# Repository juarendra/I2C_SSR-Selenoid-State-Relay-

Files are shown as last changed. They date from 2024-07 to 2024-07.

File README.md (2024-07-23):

# I2C_SSR-Selenoid-State-Relay-
## Table of Content

* [Product Specsification](#product-specsification)
* [Technical Spesification](#technical-spesification)
* [Priview Hardware](#priview-hardware)
* [Documentation](#documentation)
  * [Pinout Diagram](#pinout-diagram)
  * [Dimension](#dimension)
  * [BOM](#bom)
  * [Schematic](#schematic0)
  * [Example Program](#examples-program)
* [FAQ](#FAQ)

## Priview Hardware
<p align="center">
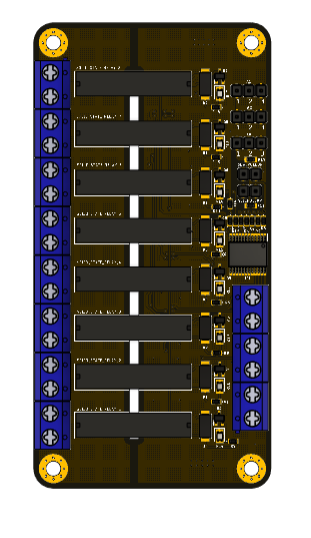
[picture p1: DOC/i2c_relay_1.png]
  
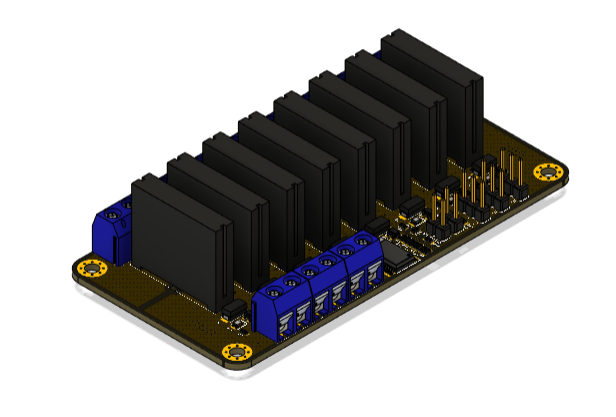
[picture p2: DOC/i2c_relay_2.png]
  
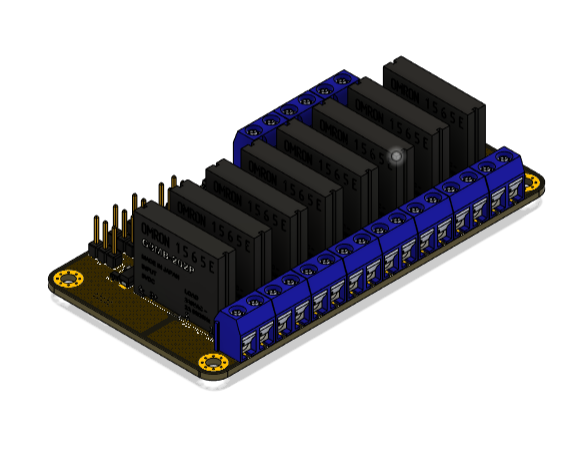
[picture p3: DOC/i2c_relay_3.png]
  
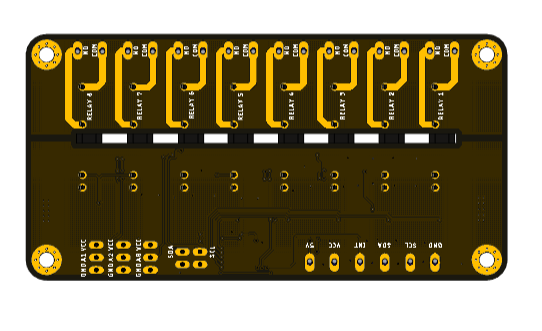
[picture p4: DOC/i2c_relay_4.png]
  
</p>

## Documentation
### Pinout Diagram
<p align="center">
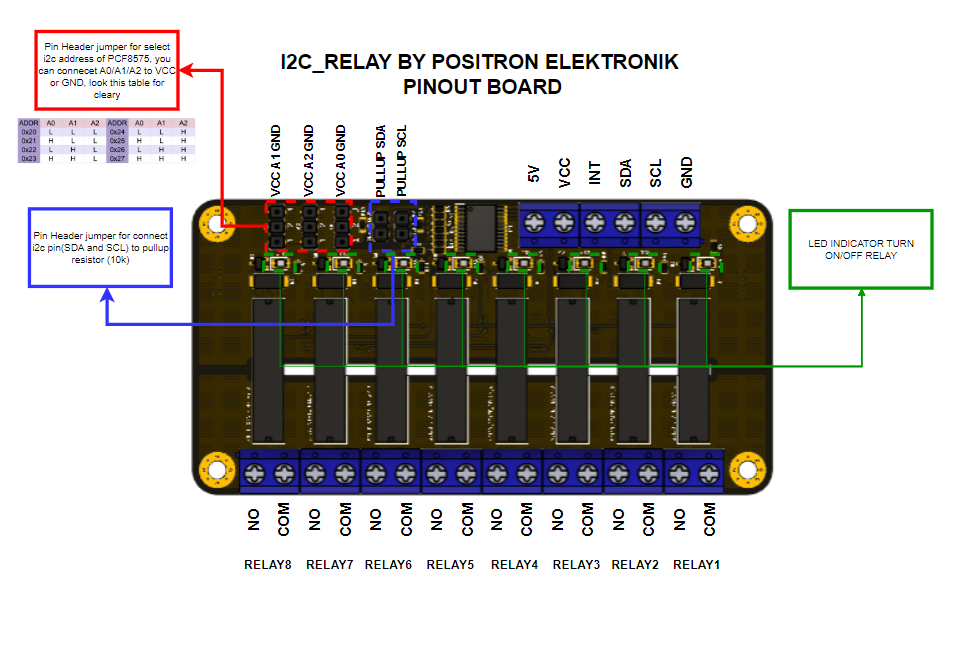
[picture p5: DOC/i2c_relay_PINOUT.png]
  
</p>

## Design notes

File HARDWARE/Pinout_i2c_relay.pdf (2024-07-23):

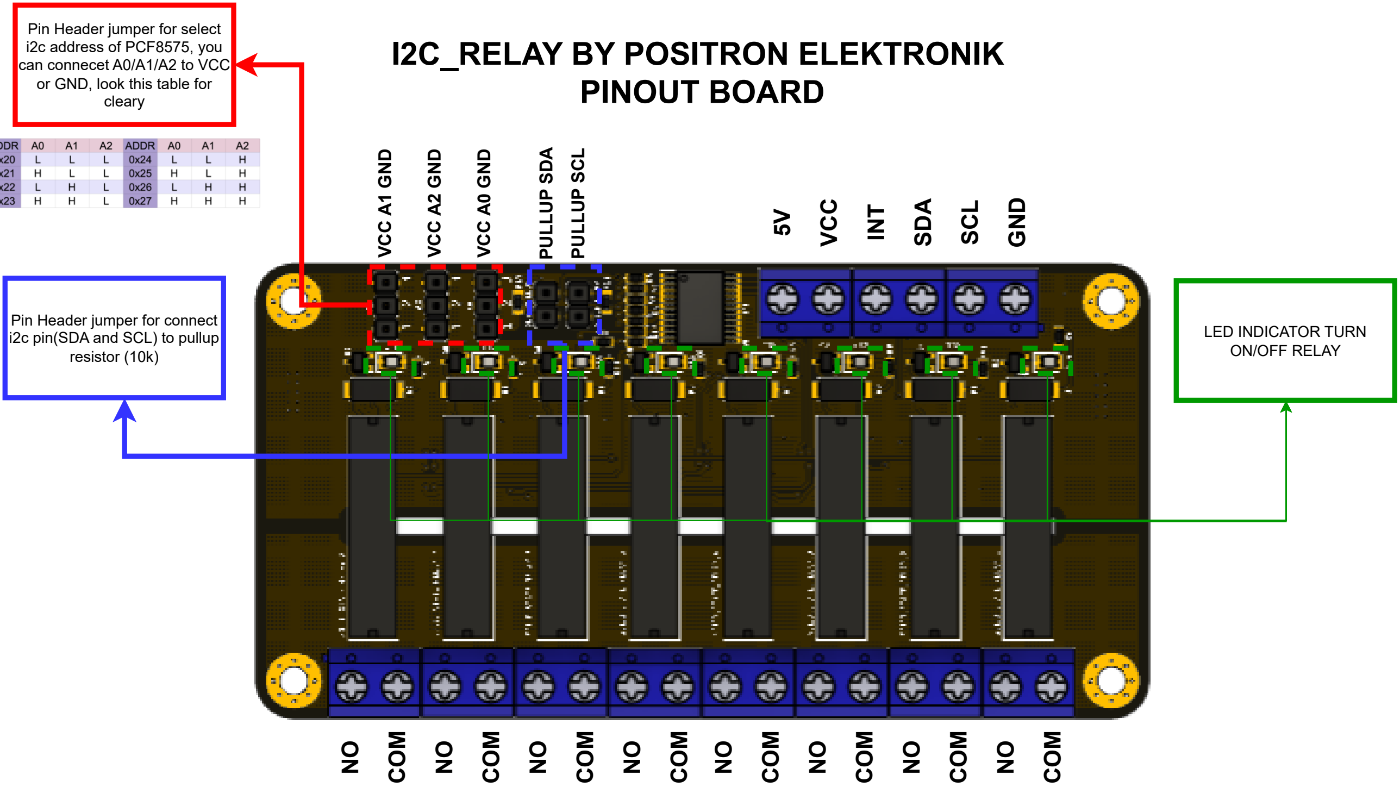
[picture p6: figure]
I2C_RELAY BY POSITRON ELEKTRONIK PINOUT BOARD; COM; VCC; INT; SDA; SCL; GND; Pin Header jumper for select i2c address of PCF8575, you can connecet A0/A1/A2 to VCC or GND, look this table for cleary; Pin Header jumper for connect i2c pin(SDA and SCL) to pullup resistor (10k); LED INDICATOR TURN ON/OFF RELAY

RELAY8 RELAY7 RELAY6 RELAY5 | RELAY4 RELAY3 RELAY2 RELAY1 VCC A¹ GND | VCC A² GND | VCC A⁰ GND | PULLUP SDA PULLUP SCL

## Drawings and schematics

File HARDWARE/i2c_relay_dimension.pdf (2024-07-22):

21.65

1.57

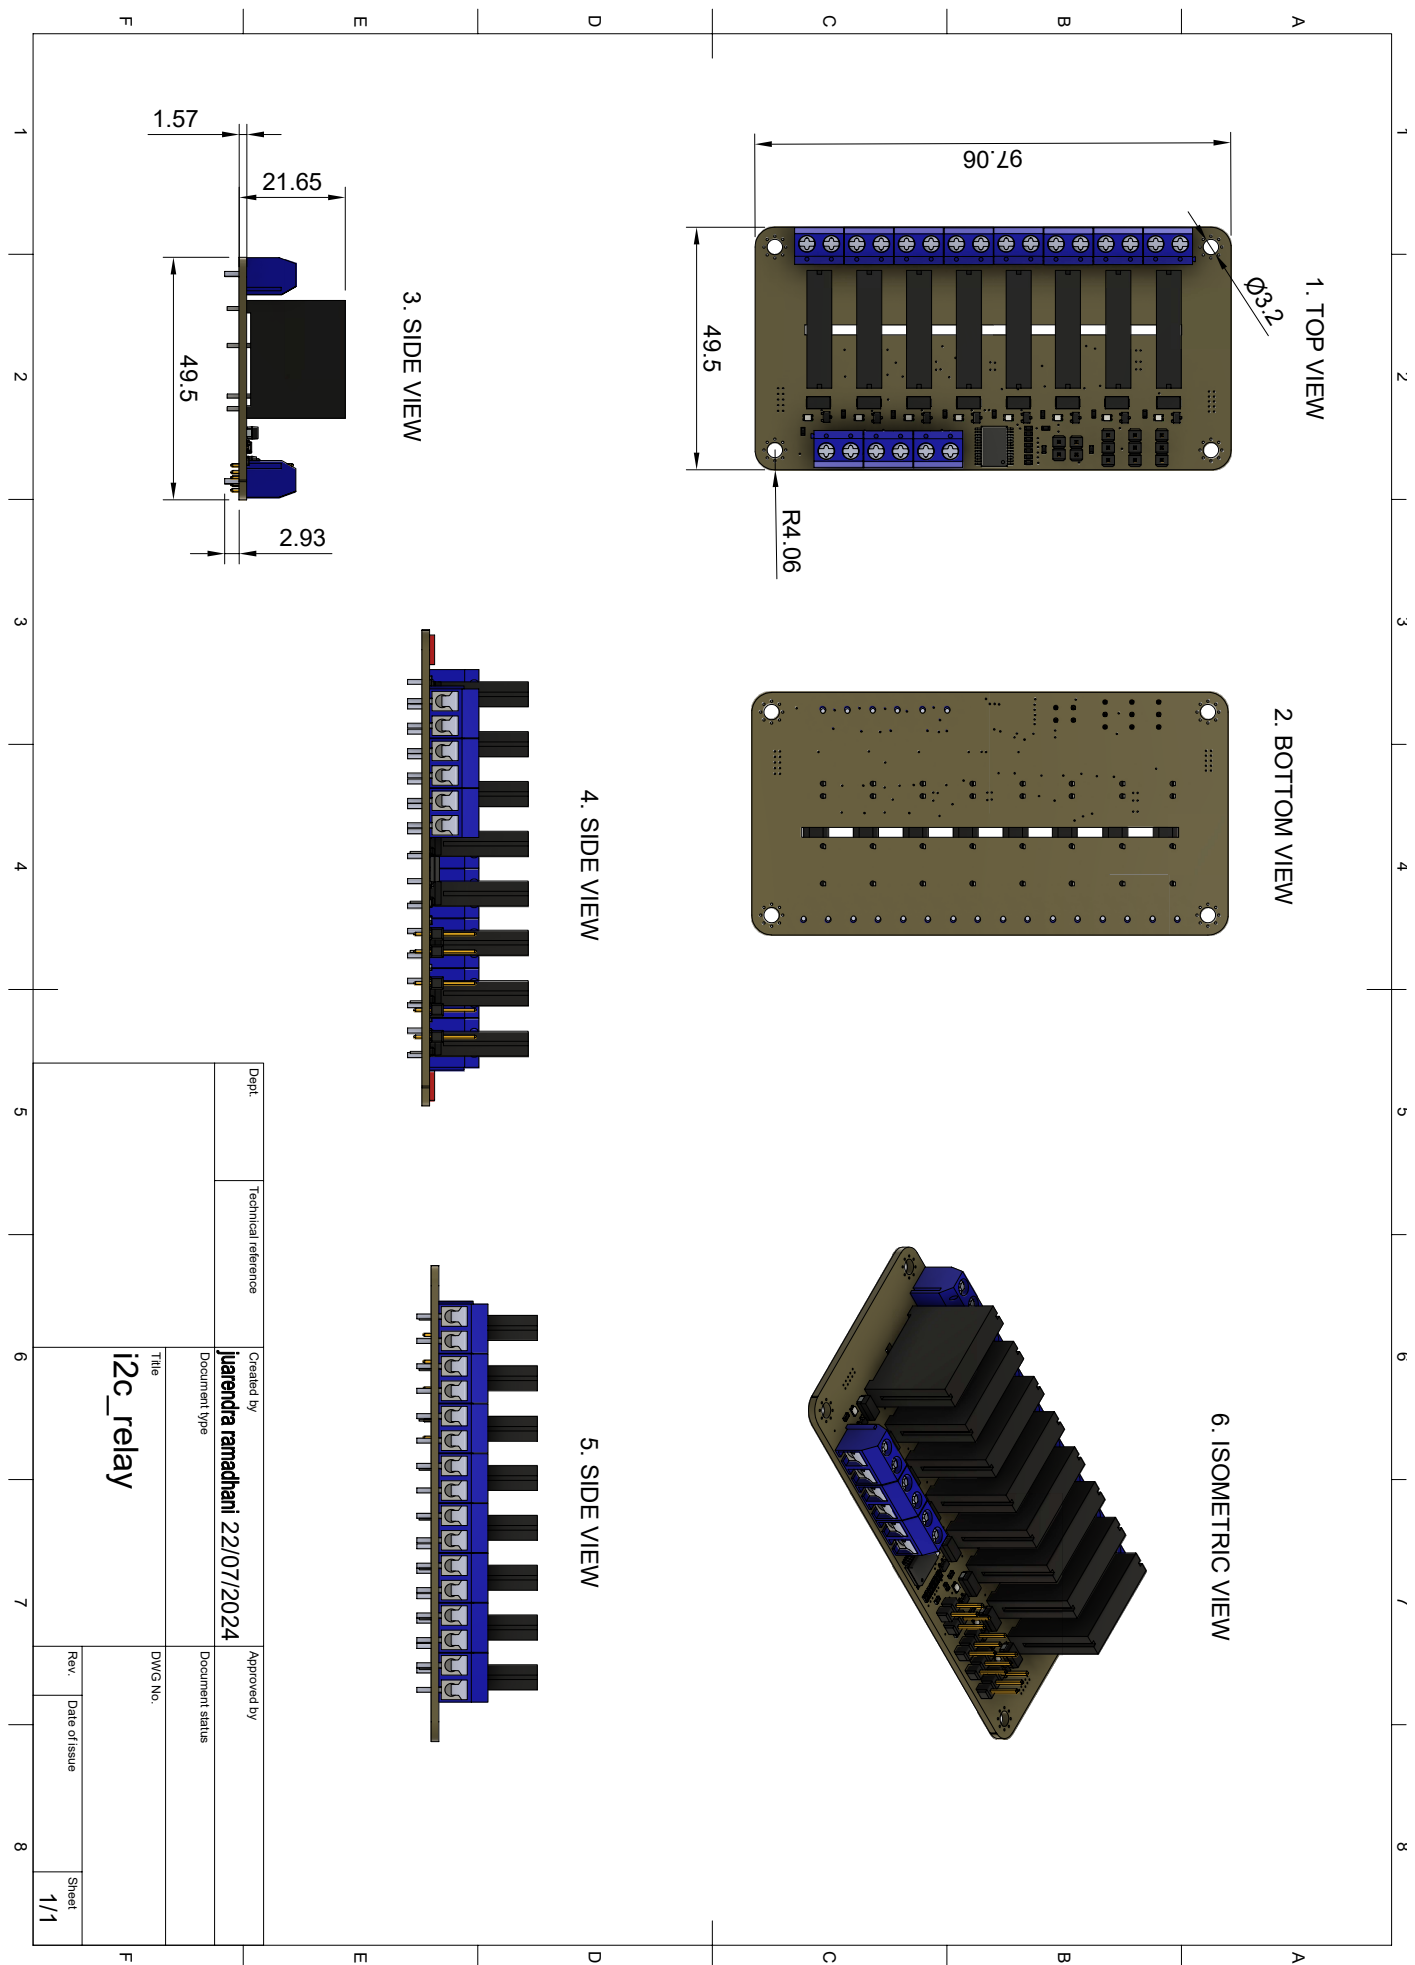
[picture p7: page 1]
1. TOP VIEW ³. SIDE VIEW; 4. SIDE VIEW 5. SIDE VIEW; 2. BOTTOM VIEW 6. ISOMETRIC VIEW

1 A 2 3 4 5 6 7 8 1 2 3 4 5 6 7 8 FEDCB FEDCBA Dept. Technical reference Created by Approved by Title DWG No. Document type Document status Rev. Date of issue Sheet 22/07/2024 1/1 i2c_relay Ø3.2

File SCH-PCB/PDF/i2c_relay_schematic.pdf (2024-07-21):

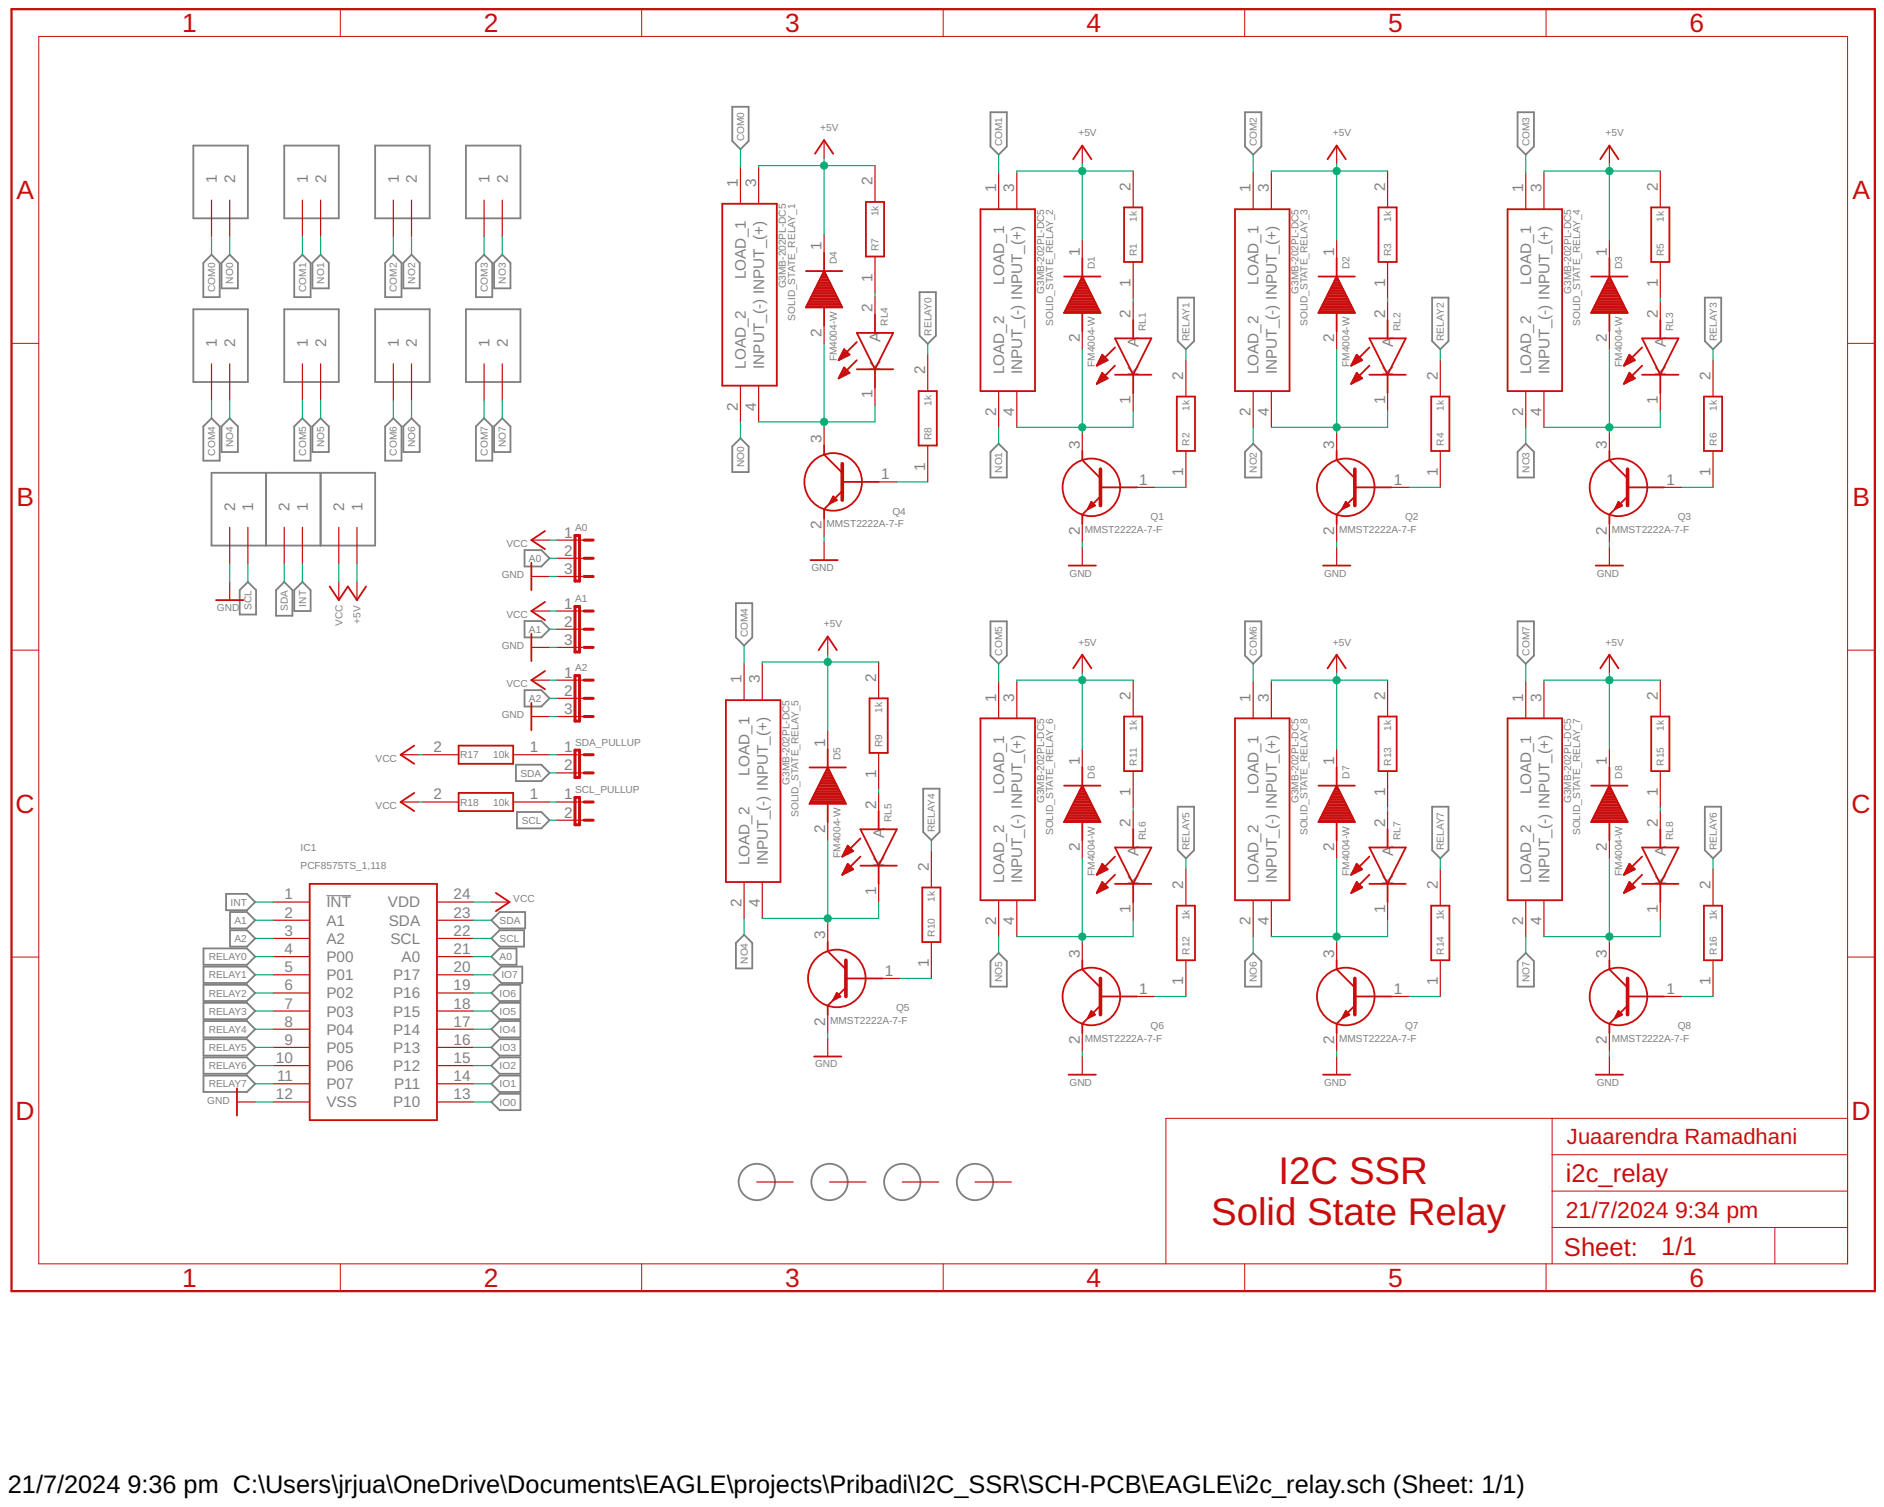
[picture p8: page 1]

21/7/2024 9:36 pm C:\Users\jrjua\OneDrive\Documents\EAGLE\projects\Pribadi\I2C_SSR\SCH-PCB\EAGLE\i2c_relay.sch (Sheet: 1/1)

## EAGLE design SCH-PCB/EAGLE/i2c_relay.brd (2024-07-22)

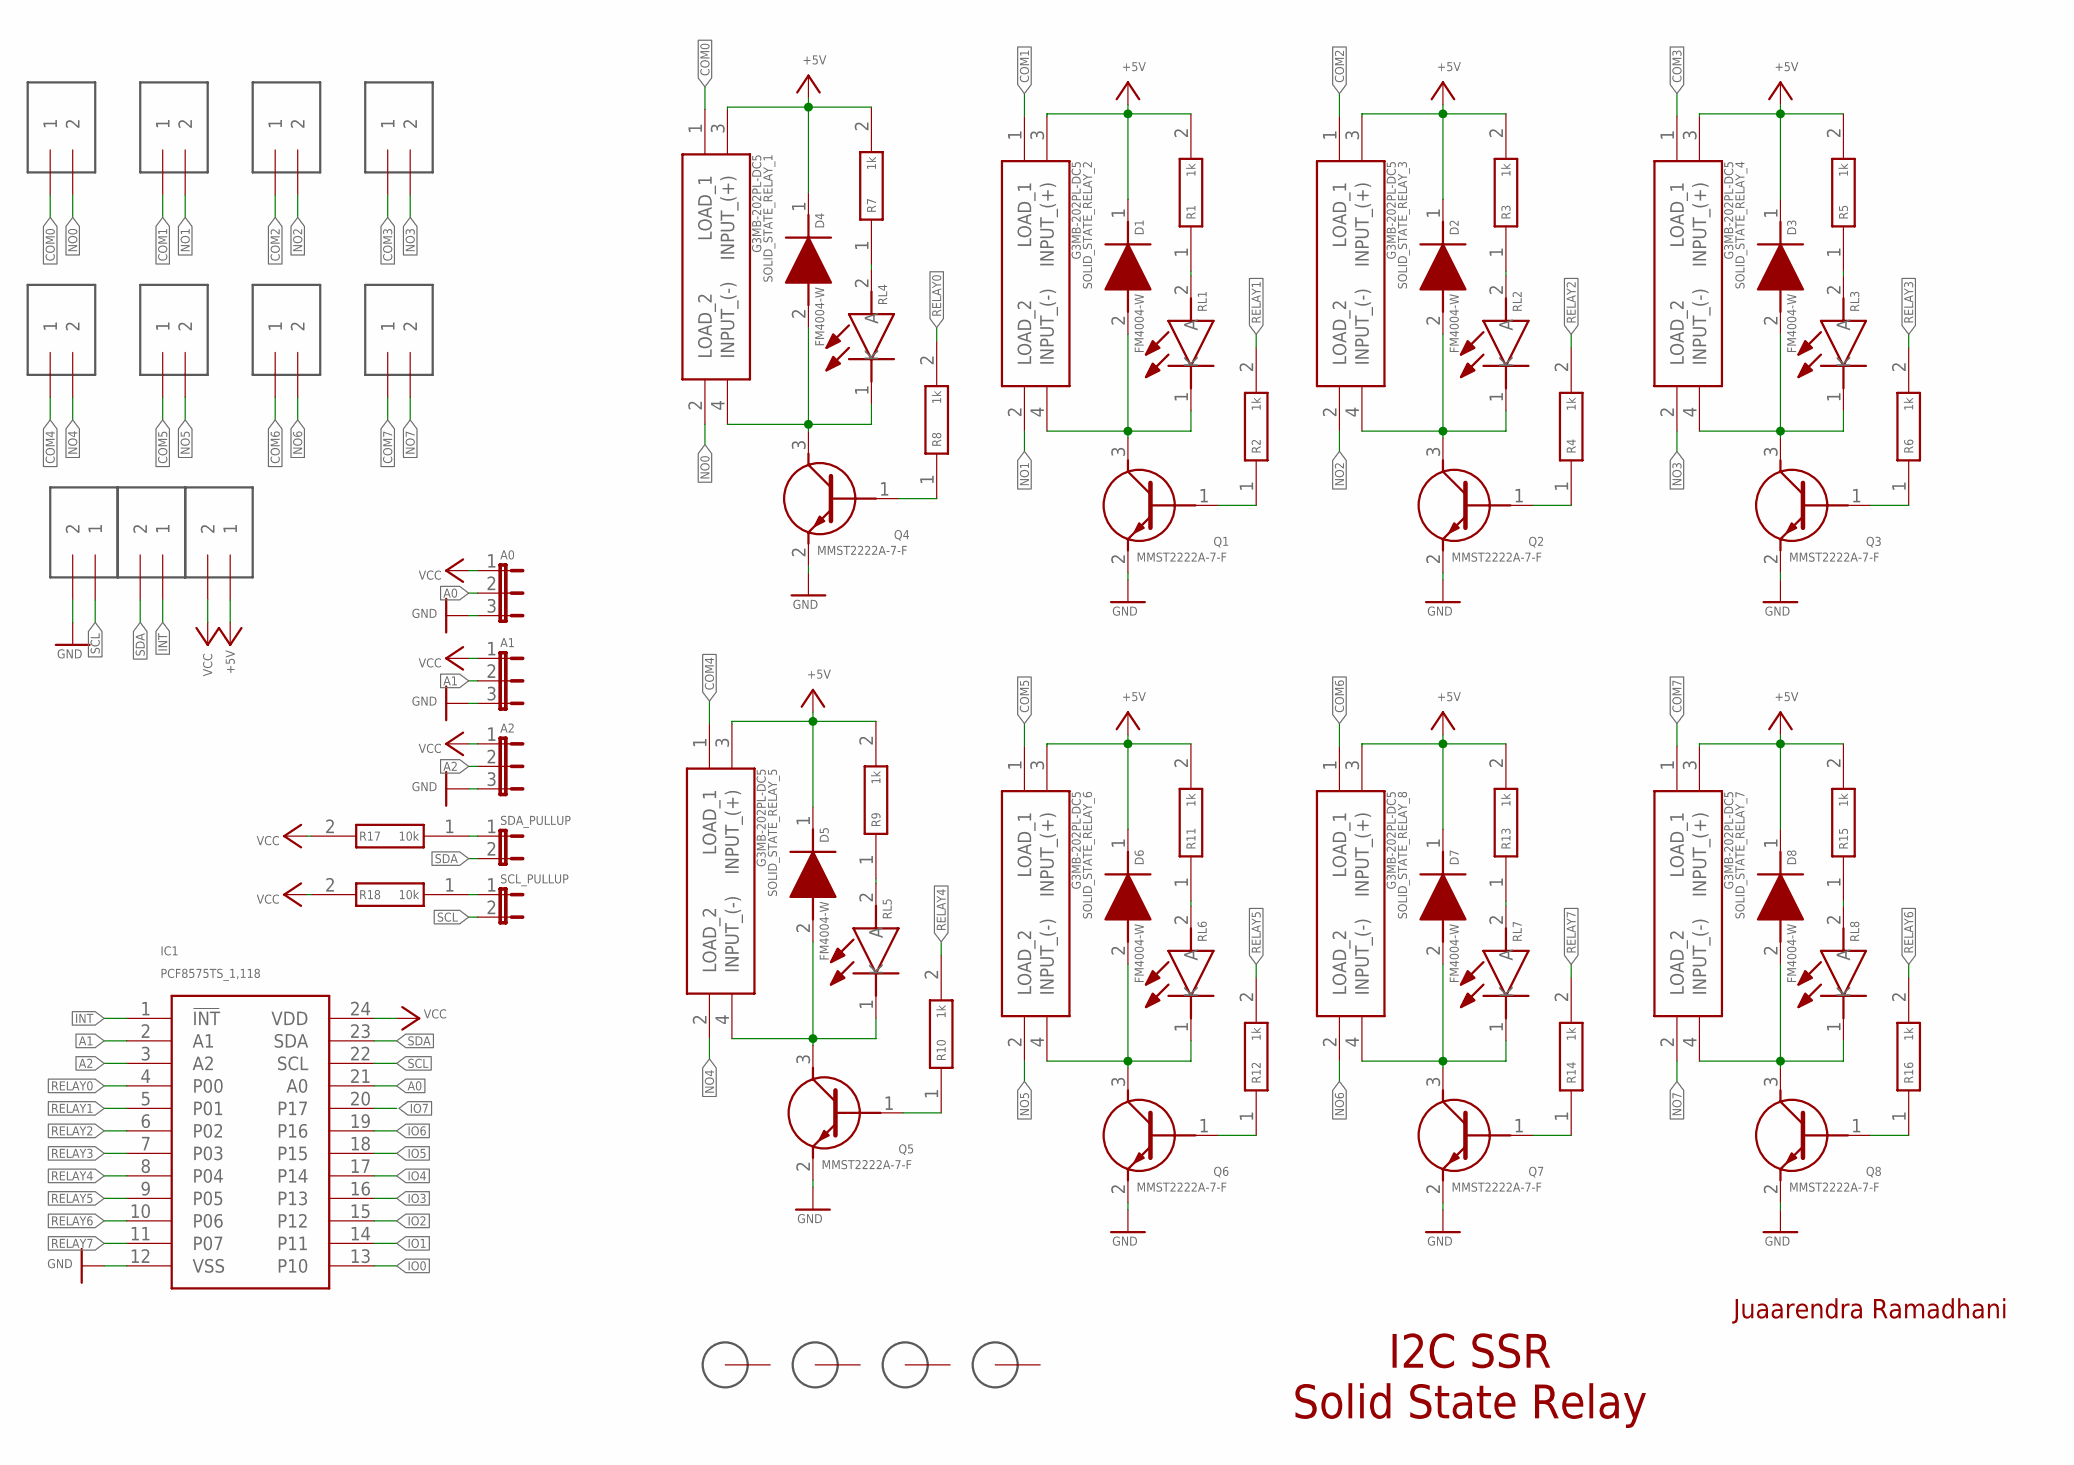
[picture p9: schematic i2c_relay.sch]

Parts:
A0, A1, A2: JP2E; JP2
D1, D2, D3, D4, D5, D6, D7, D8: FM4004-W; DIONM5025X231N
H1, H2, H3, H4: 3MM_HOLE
IC1: PCF8575TS_1,118; SOP65P775X200-24N
Q1, Q2, Q3, Q4, Q5, Q6, Q7, Q8: MMST2222A-7-F; SOT65P210X110-3N
R1, R2, R3, R4, R5, R6, R7, R8, R9, R10, R11, R12, R13, R14, R15, R16: 1k; ERA3AEB101V
R17, R18: 10k; RESC1608X55N
RL1, RL2, RL3, RL4, RL5, RL6, RL7, RL8: 150080SS75000; LEDC2012X80N
SCL_PULLUP: JP1E; JP1
SDA_PULLUP: JP1E; JP1
SOLID_STATE_RELAY_1, SOLID_STATE_RELAY_2, SOLID_STATE_RELAY_3, SOLID_STATE_RELAY_4, SOLID_STATE_RELAY_5, SOLID_STATE_RELAY_6, SOLID_STATE_RELAY_7, SOLID_STATE_RELAY_8: G3MB-202PL-DC5; G3MB202PLDC5
U$1, U$2, U$3, U$4, U$5, U$6, U$7, U$8, U$9, U$10, U$11: TERMINAL_2P; KF301-2P

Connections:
+5V: D1.1 (K), D2.1 (K), D3.1 (K), D4.1 (K), D5.1 (K), D6.1 (K), D7.1 (K), D8.1 (K), R1.2, R3.2, R5.2, R7.2, R9.2, R11.2, R13.2, R15.2, SOLID_STATE_RELAY_1.3 (INPUT_(+)), SOLID_STATE_RELAY_2.3 (INPUT_(+)), SOLID_STATE_RELAY_3.3 (INPUT_(+)), SOLID_STATE_RELAY_4.3 (INPUT_(+)), SOLID_STATE_RELAY_5.3 (INPUT_(+)), SOLID_STATE_RELAY_6.3 (INPUT_(+)), SOLID_STATE_RELAY_7.3 (INPUT_(+)), SOLID_STATE_RELAY_8.3 (INPUT_(+)), U$11.1
A0: A0.2, IC1.21 (A0)
A1: A1.2, IC1.2 (A1)
A2: A2.2, IC1.3 (A2)
COM0: SOLID_STATE_RELAY_1.1 (LOAD_1), U$1.1
COM1: SOLID_STATE_RELAY_2.1 (LOAD_1), U$2.1
COM2: SOLID_STATE_RELAY_3.1 (LOAD_1), U$3.1
COM3: SOLID_STATE_RELAY_4.1 (LOAD_1), U$4.1
COM4: SOLID_STATE_RELAY_5.1 (LOAD_1), U$5.1
COM5: SOLID_STATE_RELAY_6.1 (LOAD_1), U$6.1
COM6: SOLID_STATE_RELAY_8.1 (LOAD_1), U$7.1
COM7: SOLID_STATE_RELAY_7.1 (LOAD_1), U$8.1
GND: A0.3, A1.3, A2.3, IC1.12 (VSS), Q1.2 (E), Q2.2 (E), Q3.2 (E), Q4.2 (E), Q5.2 (E), Q6.2 (E), Q7.2 (E), Q8.2 (E), U$9.2
INT: IC1.1 (!INT), U$10.1
IO0: IC1.13 (P10)
IO1: IC1.14 (P11)
IO2: IC1.15 (P12)
IO3: IC1.16 (P13)
IO4: IC1.17 (P14)
IO5: IC1.18 (P15)
IO6: IC1.19 (P16)
IO7: IC1.20 (P17)
unnamed: R1.1, RL1.2 (A)
unnamed: D1.2 (A), Q1.3 (C), RL1.1 (K), SOLID_STATE_RELAY_2.4 (INPUT_(-))
unnamed: Q1.1 (B), R2.1
unnamed: R3.1, RL2.2 (A)
unnamed: D2.2 (A), Q2.3 (C), RL2.1 (K), SOLID_STATE_RELAY_3.4 (INPUT_(-))
unnamed: Q2.1 (B), R4.1
unnamed: R5.1, RL3.2 (A)
unnamed: D3.2 (A), Q3.3 (C), RL3.1 (K), SOLID_STATE_RELAY_4.4 (INPUT_(-))
unnamed: Q3.1 (B), R6.1
unnamed: R7.1, RL4.2 (A)
unnamed: D4.2 (A), Q4.3 (C), RL4.1 (K), SOLID_STATE_RELAY_1.4 (INPUT_(-))
unnamed: Q4.1 (B), R8.1
unnamed: R9.1, RL5.2 (A)
unnamed: D5.2 (A), Q5.3 (C), RL5.1 (K), SOLID_STATE_RELAY_5.4 (INPUT_(-))
unnamed: Q5.1 (B), R10.1
unnamed: R11.1, RL6.2 (A)
unnamed: D6.2 (A), Q6.3 (C), RL6.1 (K), SOLID_STATE_RELAY_6.4 (INPUT_(-))
unnamed: Q6.1 (B), R12.1
unnamed: R13.1, RL7.2 (A)
unnamed: D7.2 (A), Q7.3 (C), RL7.1 (K), SOLID_STATE_RELAY_8.4 (INPUT_(-))
unnamed: Q7.1 (B), R14.1
unnamed: R15.1, RL8.2 (A)
unnamed: D8.2 (A), Q8.3 (C), RL8.1 (K), SOLID_STATE_RELAY_7.4 (INPUT_(-))
unnamed: Q8.1 (B), R16.1
unnamed: R17.1, SDA_PULLUP.1
unnamed: R18.1, SCL_PULLUP.1
NO0: SOLID_STATE_RELAY_1.2 (LOAD_2), U$1.2
NO1: SOLID_STATE_RELAY_2.2 (LOAD_2), U$2.2
NO2: SOLID_STATE_RELAY_3.2 (LOAD_2), U$3.2
NO3: SOLID_STATE_RELAY_4.2 (LOAD_2), U$4.2
NO4: SOLID_STATE_RELAY_5.2 (LOAD_2), U$5.2
NO5: SOLID_STATE_RELAY_6.2 (LOAD_2), U$6.2
NO6: SOLID_STATE_RELAY_8.2 (LOAD_2), U$7.2
NO7: SOLID_STATE_RELAY_7.2 (LOAD_2), U$8.2
RELAY0: IC1.4 (P00), R8.2
RELAY1: IC1.5 (P01), R2.2
RELAY2: IC1.6 (P02), R4.2
RELAY3: IC1.7 (P03), R6.2
RELAY4: IC1.8 (P04), R10.2
RELAY5: IC1.9 (P05), R12.2
RELAY6: IC1.10 (P06), R16.2
RELAY7: IC1.11 (P07), R14.2
SCL: IC1.22 (SCL), SCL_PULLUP.2, U$9.1
SDA: IC1.23 (SDA), SDA_PULLUP.2, U$10.2
VCC: A0.1, A1.1, A2.1, IC1.24 (VDD), R17.2, R18.2, U$11.2

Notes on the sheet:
I2C SSR Solid State Relay
Juaarendra Ramadhani

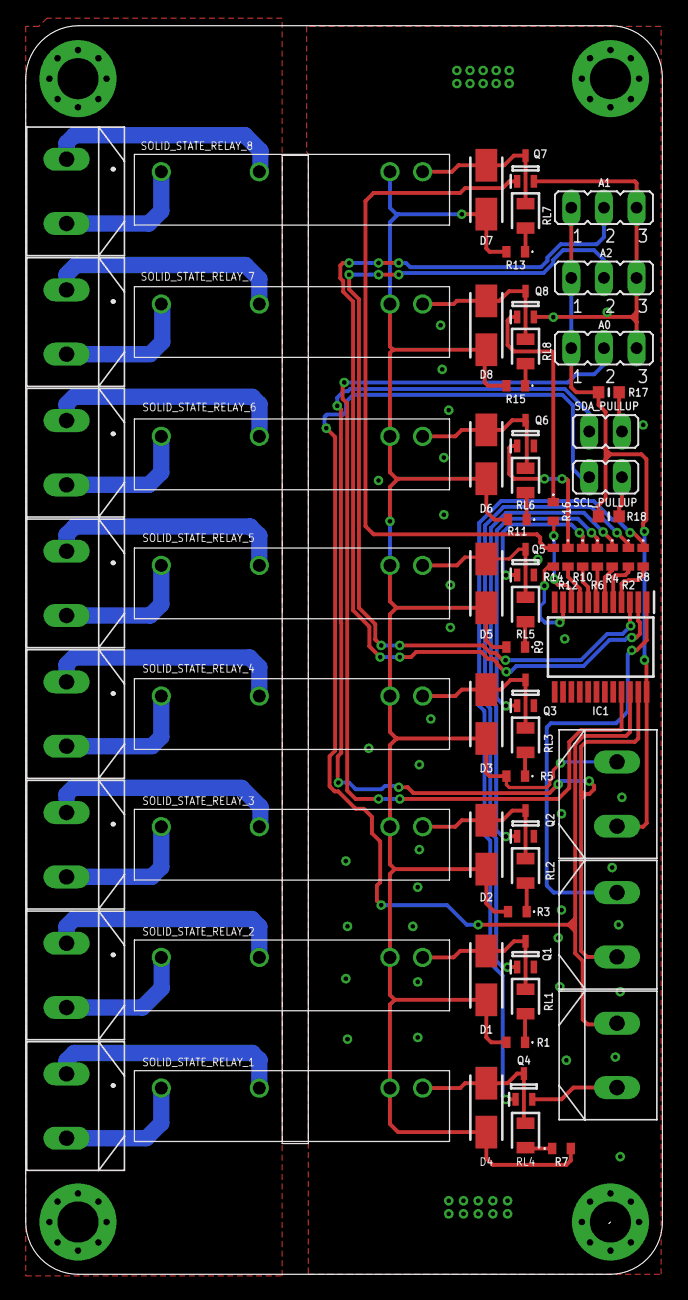
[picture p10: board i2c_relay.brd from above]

Board: 2 copper layers, 49.5 x 97.1 mm, 71 parts (0 on the bottom side), 59 nets.

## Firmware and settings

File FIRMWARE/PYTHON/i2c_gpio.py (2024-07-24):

import smbus
import time

DEV_PCF_ADDRS = 0x20

i2c_device = None


def read_gpio_all(device_bus=0):
    """"""
    i2c_device = smbus.SMBus(device_bus)
    #
    data = []
    data.append(i2c_device.read_word_data(DEV_PCF_ADDRS, 0))
    i2c_device.close()
    #
    return data


def write_gpio_all(data, device_bus=0):
    """"""
    i2c_device = smbus.SMBus(device_bus)

    data_b = data.to_bytes(2, byteorder='little')
    i2c_device.write_byte_data(DEV_PCF_ADDRS, data_b[0], data_b[1])
    i2c_device.close()


def read_gpio_num(gpio_num, device_bus=0):
    """"""
    i2c_device = smbus.SMBus(device_bus)
    #
    if gpio_num < 1 or gpio_num > 8:
        raise ValueError("Invalid GPIO, GPIO must be in 1-8 range")
    # read corespond device
    data = i2c_device.read_word_data(DEV_PCF_ADDRS, 0)
    gpio_num = gpio_num -1
    i2c_device.close()
    #
    if (data & (0x01 << gpio_num)):
        return 1
    else:
        return 0


def write_gpio_num(gpio_num, data, device_bus=0):
    """"""
    i2c_device = smbus.SMBus(device_bus)
    #
    if gpio_num < 1 or gpio_num > 8:
        raise ValueError("Invalid GPIO, GPIO must be in 0-63 range")
    # read corespond device
    data_read = i2c_device.read_word_data(DEV_PCF_ADDRS, 0)
    #
    gpio_num = gpio_num - 1
    if data:
        data_write = data_read | (0x01 << gpio_num)
    else:
        data_write = data_read & (~(0x01 << gpio_num))
    #
    data_b = data_write.to_bytes(2, byteorder='little')
    i2c_device.write_byte_data(DEV_PCF_ADDRS, data_b[0], data_b[1])
    #
    i2c_device.close()


print("Turn ON single relay 1")
write_gpio_num(1, 0x01)
time.sleep(1)
print("Turn ON single relay 2")
write_gpio_num(2, 0x01)
time.sleep(1)
print("Turn ON single relay 3")
write_gpio_num(3, 0x01)
time.sleep(1)
print("Turn ON single relay 4")
write_gpio_num(4, 0x01)
time.sleep(1)
print("Turn ON single relay 5")
write_gpio_num(5, 0x01)
time.sleep(1)
print("Turn ON single relay 6")
write_gpio_num(6, 0x01)
time.sleep(1)
print("Turn ON single relay 7")
write_gpio_num(7, 0x01)
time.sleep(1)
print("Turn ON single relay 8")
write_gpio_num(8, 0x01)
time.sleep(1)
print("Turn OFF single relay 1")
write_gpio_num(1, 0x00)
time.sleep(1)
print("Turn OFF single relay 2")
write_gpio_num(2, 0x00)
time.sleep(1)
print("Turn OFF single relay 3")
write_gpio_num(3, 0x00)
time.sleep(1)
print("Turn OFF single relay 4")
write_gpio_num(4, 0x00)
time.sleep(1)
print("Turn OFF single relay 5")
write_gpio_num(5, 0x00)
time.sleep(1)
print("Turn OFF single relay 6")
write_gpio_num(6, 0x00)
time.sleep(1)
print("Turn OFF single relay 7")
write_gpio_num(7, 0x00)
time.sleep(1)
print("Turn OFF single relay 8")
write_gpio_num(8, 0x00)
time.sleep(1)

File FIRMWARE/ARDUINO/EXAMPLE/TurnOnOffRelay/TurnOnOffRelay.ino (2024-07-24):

/*
 Blink led on PIN0
 by Mischianti Renzo <http://www.mischianti.org>

 https://www.mischianti.org/2019/01/02/pcf8575-i2c-digital-i-o-expander-fast-easy-usage/
*/

#include "Arduino.h"
#include "PCF8575.h"

// Set i2c address
PCF8575 pcf8575(0x20);

// define pin pcf8575

#define relay1 0
#define relay2 1
#define relay3 2
#define relay4 3
#define relay5 4
#define relay6 5
#define relay7 6
#define relay8 7

void setup()
{
	Serial.begin(115200);
  Serial.println("Example Relay I2C by Positron Elektronik");

	// Set pinMode to OUTPUT
	pcf8575.pinMode(relay1, OUTPUT);
	pcf8575.pinMode(relay2, OUTPUT);
	pcf8575.pinMode(relay3, OUTPUT);
	pcf8575.pinMode(relay4, OUTPUT);
	pcf8575.pinMode(relay5, OUTPUT);
	pcf8575.pinMode(relay6, OUTPUT);
	pcf8575.pinMode(relay7, OUTPUT);
	pcf8575.pinMode(relay8, OUTPUT);

	pcf8575.begin();
}

void loop()
{
  Serial.println("Turn On Relay 1");
	pcf8575.digitalWrite(relay1, HIGH);
	delay(1000);
  Serial.println("Turn On Relay 2");
	pcf8575.digitalWrite(relay2, HIGH);
	delay(1000);
  Serial.println("Turn On Relay 3");
	pcf8575.digitalWrite(relay3, HIGH);
	delay(1000);
  Serial.println("Turn On Relay 4");
	pcf8575.digitalWrite(relay4, HIGH);
	delay(1000);
  Serial.println("Turn On Relay 5");
	pcf8575.digitalWrite(relay5, HIGH);
	delay(1000);
  Serial.println("Turn On Relay 6");
	pcf8575.digitalWrite(relay6, HIGH);
	delay(1000);
  Serial.println("Turn On Relay 7");
	pcf8575.digitalWrite(relay7, HIGH);
	delay(1000);
  Serial.println("Turn On Relay 8");
	pcf8575.digitalWrite(relay8, HIGH);
	delay(1000);
  Serial.println("Turn Off Relay 1");
	pcf8575.digitalWrite(relay1, LOW);
	delay(1000);
  Serial.println("Turn Off Relay 2");
	pcf8575.digitalWrite(relay2, LOW);
	delay(1000);
  Serial.println("Turn Off Relay 3");
	pcf8575.digitalWrite(relay3, LOW);
	delay(1000);
  Serial.println("Turn Off Relay 4");
	pcf8575.digitalWrite(relay4, LOW);
	delay(1000);
  Serial.println("Turn Off Relay 5");
	pcf8575.digitalWrite(relay5, LOW);
	delay(1000);
  Serial.println("Turn Off Relay 6");
	pcf8575.digitalWrite(relay6, LOW);
	delay(1000);
  Serial.println("Turn Off Relay 7");
	pcf8575.digitalWrite(relay7, LOW);
	delay(1000);
  Serial.println("Turn Off Relay 8");
	pcf8575.digitalWrite(relay8, LOW);
	delay(1000);
}

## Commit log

2024-07-21 FEAT: add board pcb
    [i2c_relay.brd]
2024-07-21 FEAT: add 3d and push to FUSION360
    [i2c_relay.brd, i2c_relay.sch]
2024-07-21 FEAT: change folder
    [i2c_relay.brd, i2c_relay.sch]
2024-07-21 FEAT: add pdf schematic
2024-07-21 FEAT: add gerber
    [copper_bottom.gbr, copper_top.gbr, drill_1_16.xln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]
2024-07-22 FEAT: update silkscreen board pcb
    [i2c_relay.brd, i2c_relay.sch]
2024-07-22 FEAT: update gerber
    [copper_bottom.gbr, copper_top.gbr, drill_1_16.xln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]
